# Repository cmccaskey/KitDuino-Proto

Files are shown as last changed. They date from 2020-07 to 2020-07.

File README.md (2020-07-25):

# About #
Thunkit Electronics sells electronic kits and rocket altimeters, available at [thunkitelectronics.com](https://thunkitelectronics.com) and [Tindie](https://www.tindie.com/stores/cmccaskey). All designs are open source with schematics, board layouts, code, and BOMs available. The Creative Commons Attribution-NonCommercial-ShareAlike 4.0 International License is used and can be read [here]( https://creativecommons.org/licenses/by-nc-sa/4.0/legalcode).

## Description ###
image goes here <br />
The KitDuino Proto is a 32u4 Arduino compatible with built in prototyping area. The board supports 3 voltage modes selectable by jumpers: 3.3V regulated, 5V regulated, and Vin direct with no regulation.

## Why KitDuino Proto? ## 
The KitDuino Proto is a one of a kind Arduino compatible board. It uses the Atmel ATmega32u4 and can be programmed by the Arduino IDE using the Thunkit Arduino Core available [here](https://github.com/cmccaskey/Thunkit-Arduino-Core/tree/master).The KitDuino Proto has a small prototyping area making it a great addition to your next project.

## Technical Specifications ##
The KitDuino Proto runs at 8MHz to allow for 3.3V and 5V operation. The KitDuino Proto supports 3 voltage modes. By default, the board will run at 3.3V. By installing the jumper in the '5V SEL' position, the board will run at 5V. When powered over USB, due to losses in the regulator circuit, the board will run at approximately 3.8V. If an external voltage sorce of 7V or higher is used, a stable 5V rail will be generated by the regulator. For projects that are always powered off of USB and never see a Vin of more than 5V, the 'Vin SEL' jumper can be installed. This jumper directly connects the USB voltage (after schottky diode) to VCC. Beware! Installing the 'Vin SEL' jumper and connecting a Vin of more than 5V can cause permanent damage to your board!

## BOM ##
KiCad interactive BOM available at [thunkitelectronics.com](https://thunkitelectronics.com).

## Schematic ##
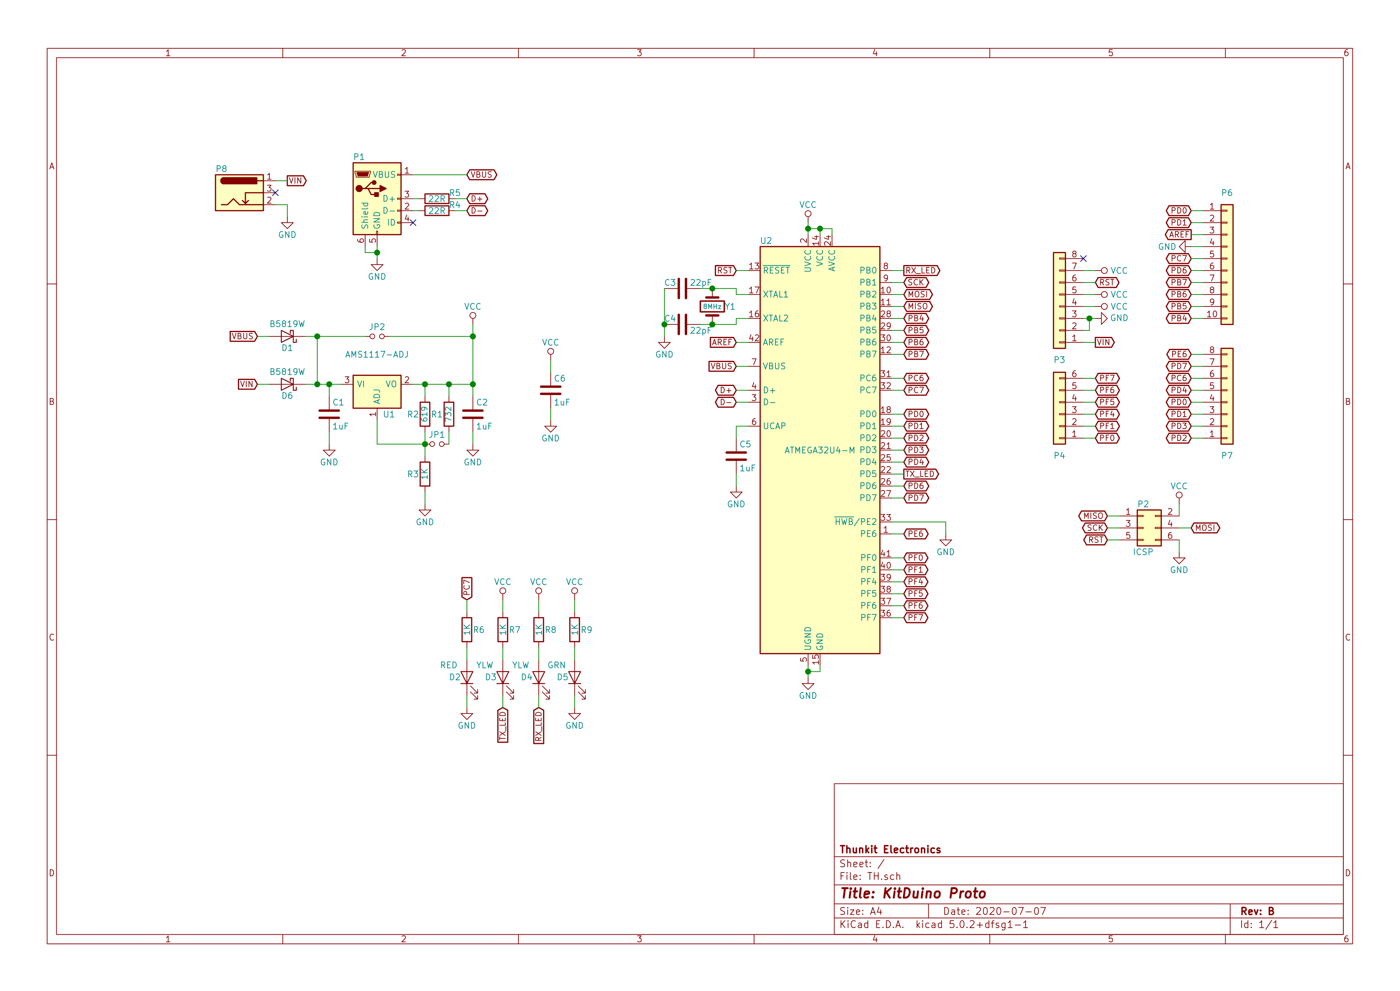
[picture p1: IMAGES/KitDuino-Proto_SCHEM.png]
image goes here
 <br />

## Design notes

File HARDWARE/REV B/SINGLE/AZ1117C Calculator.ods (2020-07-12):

VREF | IADJ | R1 | R2 | VOUT
1.25 | 5.00E-05 | 330 | 1000 | 5.08787878787879 | R1 | R2
 |  |  |  |  | 330 | 1000
VREF | IADJ | R1 | R2 | VOUT | R1*
1.25 | 5.00E-05 | 620 | 1000 | 3.31612903225806 | #DIV/0!
VREF | IADJ | R1 | R2 | VOUT | Actual Values Used
1.25 | 5.00E-05 | 619 | 1000 | 3.31938610662359 | R1 | 619
 |  |  |  |  | R2 | 1000
 |  |  |  |  | R1* | 732
VREF | IADJ | R1 | R2 | VOUT
1.25 | 5.00E-05 | 335.387120651369 | 1000 | 5.02703637984763
Minimum Load Current
0.01 | (A) |  | 3.31938610662359 | (V) | 5.02703637984763 | (V) | Power LED pushes into minimum load current
3.3 | (V) |  | 1619 | (Ohms) | 1335.38712065137 | (Ohms)
330 | (Ohms) |  | 0.002050269367896 | (mA) | 0.003764478705917 | (mA)

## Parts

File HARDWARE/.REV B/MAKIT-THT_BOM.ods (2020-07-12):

Designator | KiCad Package | Designation | Supplier and Ref.
C1,C2,C5,C3,C4,C8 | C_Disc_D3.8mm_W2.6mm_P2.50mm | 1uF | Arrow# K105Z20Y5VF5TL2
C6,C7 | C_Disc_D3.8mm_W2.6mm_P2.50mm | 22pF | Arrow# K220J15C0GF5TL2
D1 | D_DO-15_P10.16mm_Horizontal | 2A | Arrow# SR206 A0G
D2 | LED_D5.0mm | LED_RED | Various
R1,R2 | R_Axial_DIN0207_L6.3mm_D2.5mm_P7.62mm_Horizontal | 1K | Arrow# CF14JT1K00
R3 | R_Axial_DIN0207_L6.3mm_D2.5mm_P7.62mm_Horizontal | 10K | Arrow# CF14JT10K0
R4 | R_Axial_DIN0207_L6.3mm_D2.5mm_P7.62mm_Horizontal | 330 | Arrow# CF14JT330R
U1 | TO-220-3_Horizontal_NO_HOLE | LM7805CT | Arrow# MC7805CTG
U2 | DIP-14_W7.62mm_LongPads | MCP2221A w/ socket | Arrow# MCP2221A-I/P
U3 | DIP-28_W7.62mm_LongPads | ATMEGA328P-P w/ socket | Arrow# ATMEGA328P-PU
U4 | TO-92_Inline_Wide | L78L33 | Arrow# L78L33ACZTR
P1 | USB_B | USB_A | Various
P2 | BARREL_JACK | BARREL_JACK | Various
P3,P4,P5,P6 | Arduino Pin Header Kit | CONN_MISC | Various
P7 | Pin_Header_Straight_2x03_Pitch2.54mm | ICSP | Various
SW1 | SW_PUSH_6mm | Push_SW | Arrow# 1825910-6
Y1 | Crystal_HC49-U_Vertical | 16MHz | Various

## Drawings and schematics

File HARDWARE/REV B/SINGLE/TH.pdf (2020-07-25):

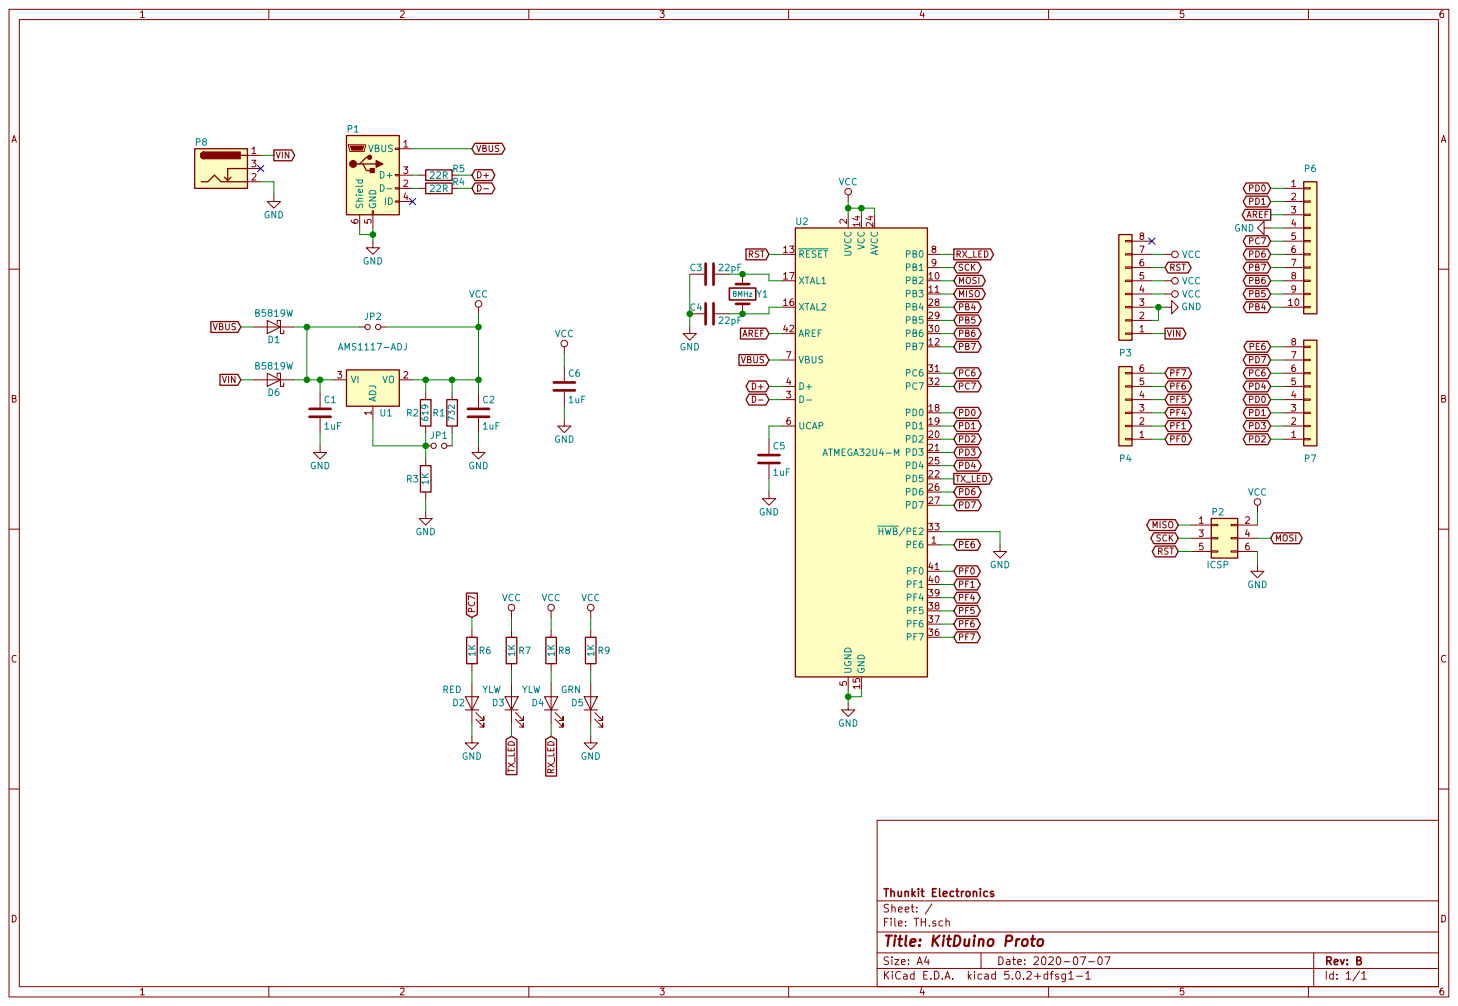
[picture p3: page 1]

2 PD2 20 PD3 21 PD5 22 AVCC 24 PD4 25 PD6 26 PD7 27 PB4 28 PB5 29 D- 3 PB6 30 PC6 31 PC7 32 HWB/PE2 33 PF7 36 PF6 37 PF5 38 PF4 39 D+ 4 PF1 40 PF0 41 AREF 42 UGND
AREF RST

File: TH.sch Sheet: / Thunkit Electronics

Id: 1/1 Title: KitDuino Proto

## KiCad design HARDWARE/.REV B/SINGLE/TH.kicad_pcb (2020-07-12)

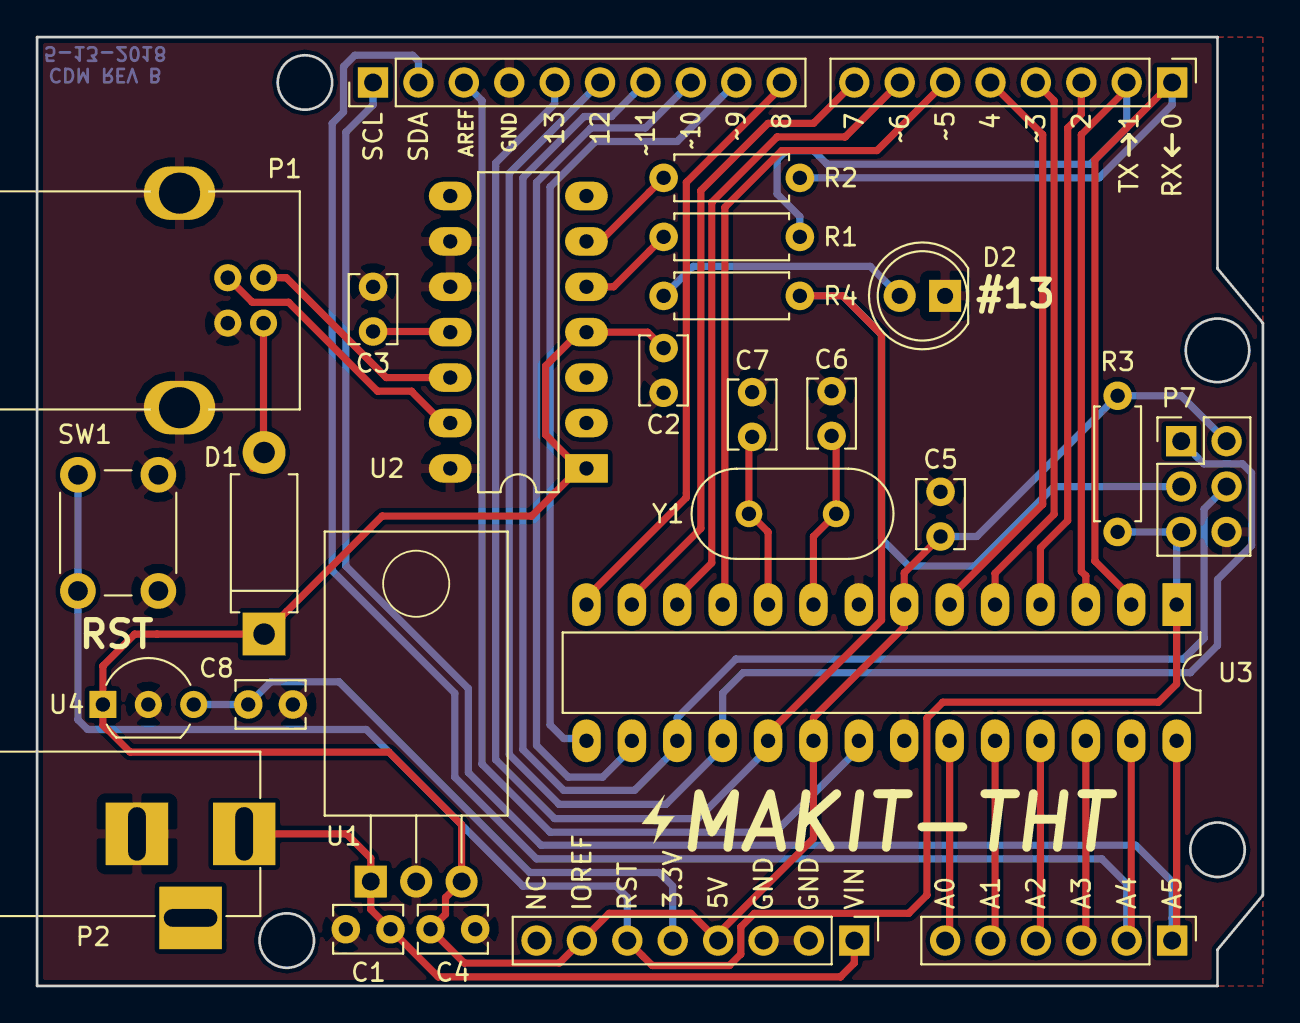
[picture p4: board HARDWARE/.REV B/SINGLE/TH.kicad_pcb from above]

Board: 2 copper layers, 68.6 x 53.1 mm, 27 parts (0 on the bottom side), 35 nets.

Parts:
C1, C2: 0.33uF; C_Disc_D3.8mm_W2.6mm_P2.50mm
C3, C4, C5, C8: 0.1uF; C_Disc_D3.8mm_W2.6mm_P2.50mm
C6, C7: 18pF; C_Disc_D3.8mm_W2.6mm_P2.50mm
D1: 2A; D_DO-15_P10.16mm_Horizontal
D2: LED; LED_D5.0mm
P1: USB_A; USB_B
P2: BARREL_JACK
P3, P6: CONN_01X08; Pin_Header_Straight_1x08_Pitch2.54mm
P4: CONN_01X06; Pin_Header_Straight_1x06_Pitch2.54mm
P5: CONN_01X10; Pin_Header_Straight_1x10_Pitch2.54mm
P7: ICSP; Pin_Header_Straight_2x03_Pitch2.54mm
R1, R2: 1K; R_Axial_DIN0207_L6.3mm_D2.5mm_P7.62mm_Horizontal
R3: 10K; R_Axial_DIN0207_L6.3mm_D2.5mm_P7.62mm_Horizontal
R4: 470; R_Axial_DIN0207_L6.3mm_D2.5mm_P7.62mm_Horizontal
SW1: Push_SW; SW_PUSH_6mm
U1: LM7805CT; TO-220-3_Horizontal_NO_HOLE
U2: MCP2221A; DIP-14_W7.62mm_LongPads
U3: ATMEGA328P-P; DIP-28_W7.62mm_LongPads
U4: L78L33; TO-92_Inline_Wide
Y1: 16MHz; Crystal_HC49-U_Vertical

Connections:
+3V3: C8.1, P3.5, U4.3
+5V: C2.2, C4.1, C5.1, D1.1, P3.4, P3.7, P7.2, R3.1, U1.3, U2.1, U2.4, U3.7, U3.20, U4.1
AREF: P5.3, U3.21
GND: C1.2, C2.1, C3.2, C4.2, C5.2, C6.1, C7.1, C8.2, D2.1, P1.4, P1.5, P2.2, P3.2, P3.3, P5.4, P7.6, SW1.2, U1.2, U2.9, U2.10, U2.14, U3.8, U3.22, U4.2
unnamed: C3.1, U2.11
unnamed: C6.2, U3.9, Y1.1
unnamed: C7.2, U3.10, Y1.2
unnamed: D1.2, P1.1
unnamed: D2.2, R4.1
unnamed: P1.2, U2.12
unnamed: P1.3, U2.13
unnamed: R1.2, U2.5
unnamed: R2.2, U2.6
PB0: P5.10, U3.14
PB1: P5.9, U3.15
PB2: P5.8, U3.16
PB3: P5.7, P7.4, U3.17
PB4: P5.6, P7.1, U3.18
PB5: P5.5, P7.3, R4.2, U3.19
PC0: P4.6, U3.23
PC1: P4.5, U3.24
PC2: P4.4, U3.25
PC3: P4.3, U3.26
PC4: P4.2, P5.2, U3.27
PC5: P4.1, P5.1, U3.28
PD0: P6.1, R2.1, U3.2
PD1: P6.2, R1.1, U3.3
PD2: P6.3, U3.4
PD3: P6.4, U3.5
PD4: P6.5, U3.6
PD5: P6.6, U3.11
PD6: P6.7, U3.12
PD7: P6.8, U3.13
RST: P3.6, P7.5, R3.2, SW1.1, U3.1
VIN: C1.1, P2.1, P3.1, U1.1

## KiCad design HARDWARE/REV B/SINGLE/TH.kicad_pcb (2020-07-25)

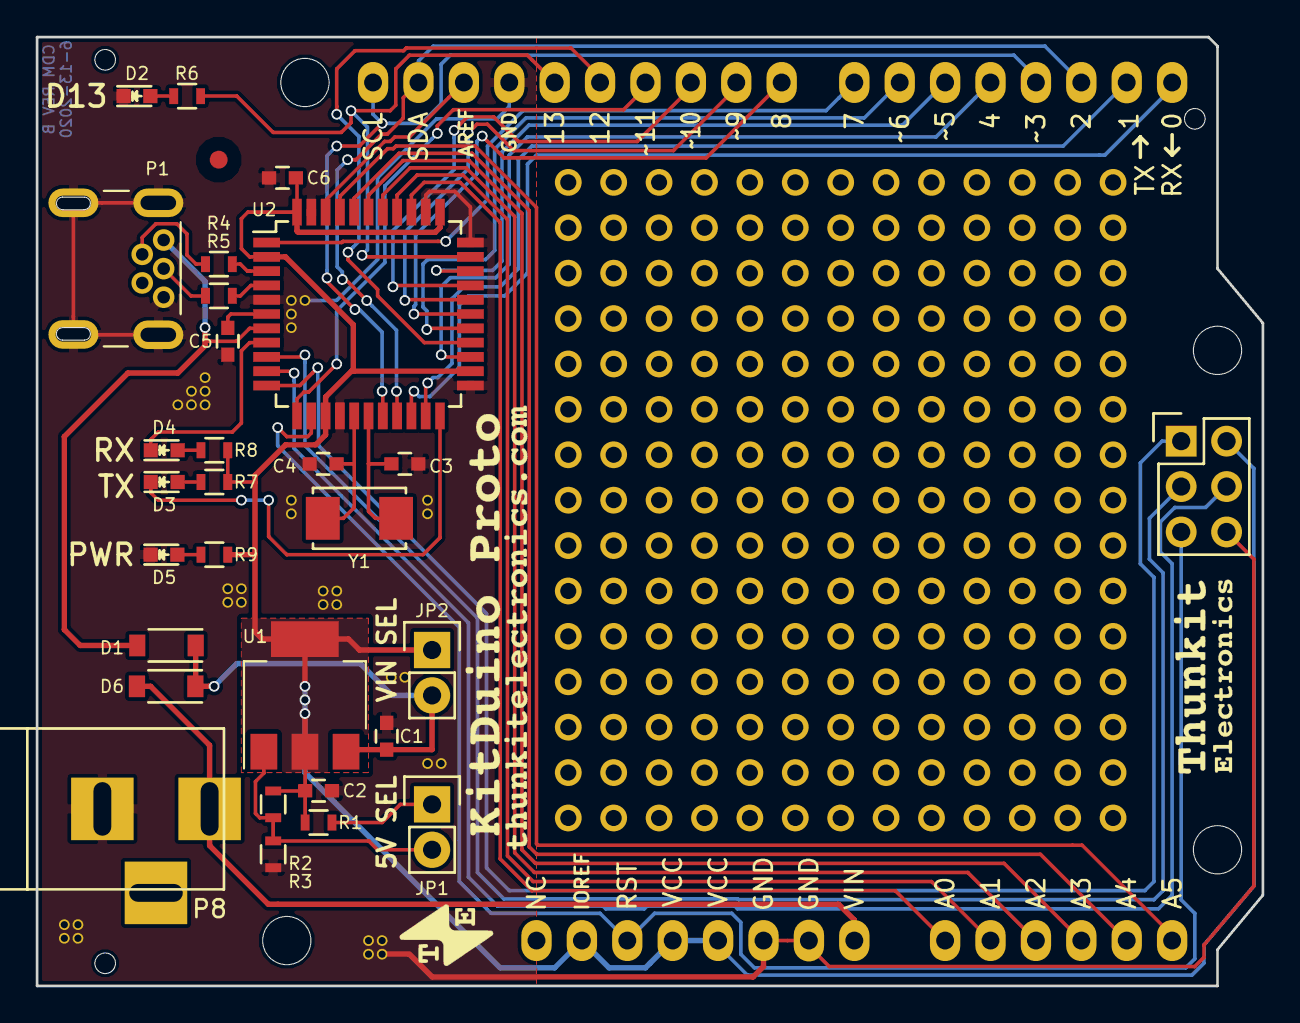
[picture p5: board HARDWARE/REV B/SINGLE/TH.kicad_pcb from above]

Board: 2 copper layers, 68.6 x 53.1 mm, 33 parts (0 on the bottom side), 45 nets.

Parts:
C1, C2, C5, C6: 1uF; C_0603
C3, C4: 22pF; C_0603
D1, D6: B5819W; SOD-123
D2: RED; LED_0603
D3, D4: YLW; LED_0603
D5: GRN; LED_0603
JP1, JP2: Jumper_NO_Small; Pin_Header_Straight_1x02
P1: USB MINI B; USB_MINI_B_TH
P2: ICSP; Pin_Header_Straight_2x03
P3, P7: CONN_01X08; Pin_Header_Straight_1x08_Pitch2.54mm_No_Silk_Long_Pads
P4: CONN_01X06; Pin_Header_Straight_1x06_Pitch2.54mm_No_Silk_Long_Pads
P6: CONN_01X10; Pin_Header_Straight_1x10_Pitch2.54mm_No_Silk_Long_Pads
P8: Barrel_Jack_Switch; BARREL_JACK
R1: 732; R_0603
R2: 619; R_0603
R3, R6, R7, R8, R9: 1K; R_0603
R4, R5: 22R; R_0603
U1: AMS1117-ADJ; SOT-223
U2: ATMEGA32U4-M; TQFP-44_10x10mm_Pitch0.8mm
Y1: 8MHz; ABM3

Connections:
AREF: P6.3, U2.42
D+: R5.1, U2.4
D-: R4.1, U2.3
GND: C1.2, C2.2, C3.1, C4.1, C5.2, C6.2, D2.1, D5.1, P1.5, P1.6, P2.6, P3.2, P3.3, P6.4, P8.2, R3.2, U2.5, U2.15, U2.23, U2.33, U2.35, U2.43
MISO: P2.1, U2.11
MOSI: P2.4, U2.10
unnamed: C1.1, D1.1, D6.1, JP2.2, U1.3
unnamed: C3.2, U2.17, Y1.1
unnamed: C4.2, U2.16, Y1.2
unnamed: C5.1, U2.6
unnamed: D2.2, R6.2
unnamed: D3.2, R7.2
unnamed: D4.2, R8.2
unnamed: D5.2, R9.2
unnamed: JP1.1, R1.2
unnamed: JP1.2, R2.2, R3.1, U1.1
unnamed: P1.2, R4.2
unnamed: P1.3, R5.2
PB4: P6.10, U2.28
PB5: P6.9, U2.29
PB6: P6.8, U2.30
PB7: P6.7, U2.12
PC6: P7.6, U2.31
PC7: P6.5, R6.1, U2.32
PD0: P6.1, P7.4, U2.18
PD1: P6.2, P7.3, U2.19
PD2: P7.1, U2.20
PD3: P7.2, U2.21
PD4: P7.5, U2.25
PD6: P6.6, U2.26
PD7: P7.7, U2.27
PE6: P7.8, U2.1
PF0: P4.1, U2.41
PF1: P4.2, U2.40
PF4: P4.3, U2.39
PF5: P4.4, U2.38
PF6: P4.5, U2.37
PF7: P4.6, U2.36
RST: P2.5, P3.6, U2.13
RX_LED: D4.1, U2.8
SCK: P2.3, U2.9
TX_LED: D3.1, U2.22
VBUS: D1.2, P1.1, U2.7
VCC: C2.1, C6.1, JP2.1, P2.2, P3.4, P3.5, P3.7, R1.1, R2.1, R7.1, R8.1, R9.1, U1.2, U1.4, U2.2, U2.14, U2.24, U2.34, U2.44
VIN: D6.2, P3.1, P8.1

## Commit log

2020-07-25 updated license, added BOM, KiCad 5
    [TH-2020-07-24-22-47-06.sch, TH.kicad_pcb]
2020-07-25 png schematic
2020-07-25 remove gitignore
    [MAKIT-THT_BOM.ods, TH.kicad_pcb, TH.sch]
